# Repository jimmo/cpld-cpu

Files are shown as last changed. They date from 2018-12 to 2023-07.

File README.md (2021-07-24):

## CPLD CPU

This is a project to create a demonstration CPU that is simple enough to be able to watch its execution but also able to do something almost useful.

It was inspired by the following five projects:
 - [Fourbit, by Jaromir Sukuba](http://jaromir.xf.cz/fourbit/fourbit.html). This is a 4-bit CPU made entirely from 74xx series logic.
 - [Tiny CPU in a CPLD, by Big Mess o' Wires](https://www.bigmessowires.com/cpu-in-a-cpld/). This implements a whole CPU inside a single Altera CPLD.
 - [MCPU, by Tim Böscke](https://github.com/cpldcpu/MCPU) (and [writeup, by Jean-Claude Wippler](https://jeelabs.org/2017/11/tfoc---a-minimal-computer/)). Similar to above, but using the exact CPLD that I was intending to use, and with a really well-documented and practical ISA.
 - [The Megaprocessor, by James Newman](http://megaprocessor.com/). "The Megaprocessor is a micro-processor built large. Very large." Each gate is made from through-hole transistors with LEDs on all inputs and outputs.
 - [monster6502, by TubeTime & Evil Mad Scientist Laboratories](https://monster6502.com/). A working replica of the 6502 using discrete SMT transistors, complete with loads of LEDs.

In particular the CPU design (ISA and architecture) is inspired by Fourbit, Tiny CPU, and especially MPU, while the exploded design and "LEDs everywhere" is inspired by the Megaprocessor and monster6502. While nowhere near as capable as monster6502 or the Megaprocessor, it is definitely much more budget-friendly! And it can still [compute prime numbers](pysim/cpu_ax_13/tests/primes.s) ([video](https://www.youtube.com/watch?v=ZP9e-FCwwOs)) and [drive APA102 LED strips](pysim/cpu_ax_13/tests/apa102c.s).

Also, while not a direct inspiration to this project, it's absolutely worth linking to [Breadboard 8-bit computer, by Ben Eater](https://eater.net/8bit) which is a wonderful series about a similar project.

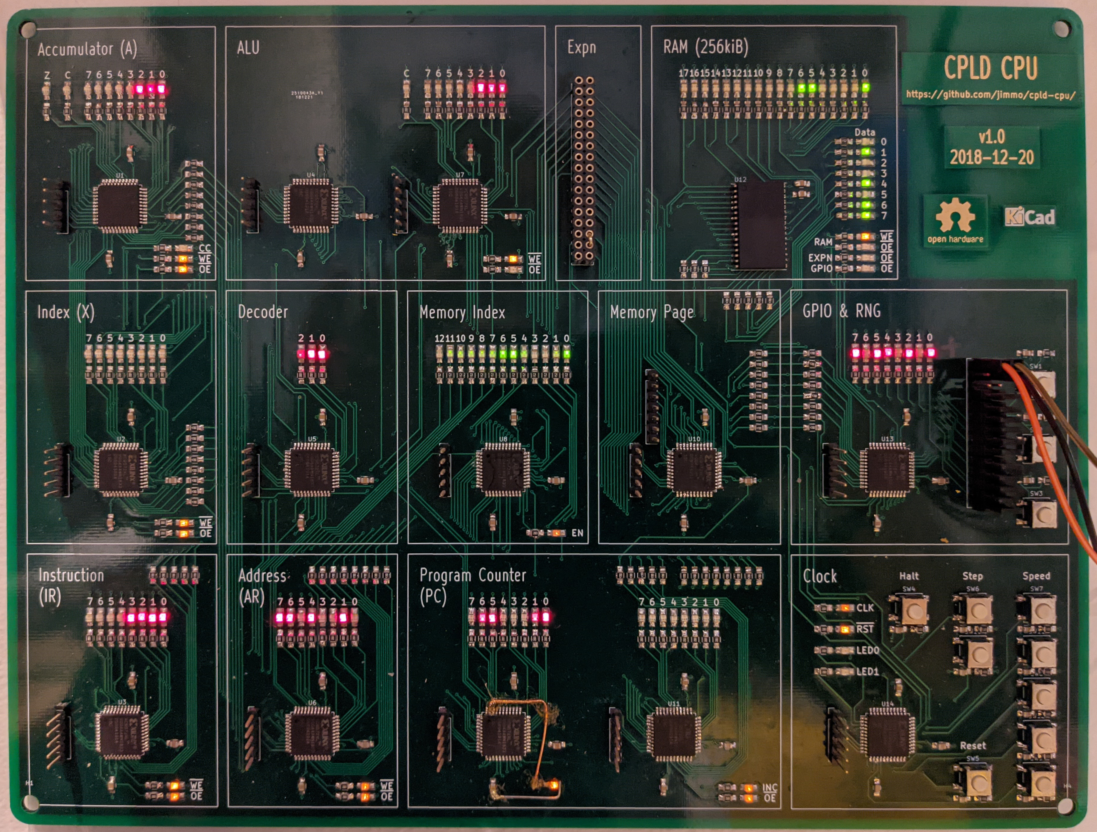
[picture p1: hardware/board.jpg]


## History

This idea started when I was teaching an introduction to "how CPUs work", and wanted something tangible to show my students. The goal is to show how simple logic circuits (i.e. starting with AND and OR gates, flip flops, and a clock) can work together to do computation. No magic required.

Initially I planned to exactly replicate the Fourbit (possibly upgraded to 8-bit), but had trouble sourcing the 74181 ALU. I found a [XC9572XL CPLD development board](http://dangerousprototypes.com/blog/2011/03/29/new-prototype-xc9572xl-cpld-development-board/) in my board collection and considered replicating the 74181 on that. CPLDs are really useful for a project like this because they do not require external flash for configuration. You can use them almost as a complete drop-in replacement. However, at this point if you're not constraining yourself to using exactly 74xx series parts, then there are several simplifications you can make in the Fourbit design.

So I set about designing a CPU where each functional component is its own CPLD. In some ways this is similar to designing a soft-CPU for an FPGA, but with the additional constraint that signals between components actually need to go via physical pins. For an 8-bit CPU, this uses up a lot of pins very quickly.

For a fun side-quest, I wrote a [logic simulator](pysim) that allows a logic circuit to be defined in Python, and simulated, much the same way that [Verilator](https://www.veripool.org/verilator/) can simulate an HDL file. This allowed me to test and iterate on some different designs, including an [exact clone of the MCPU design](pysim/cpu_a_6). Additionally the simulator allows me to stay closer to my original goal of being able to describe every logic gate, although some shortcuts were taken.

The [final design](pysim/cpu_ax_13) expands on the MCPU design, including 13-bit addressing, an index register, two-byte instruction encoding, a primitive MMU allowing addressing up to 1MiB of physical RAM, and memory-mapped IO. The memory is von Neumann, allowing for RAM and ROM to share the same bus. The simulator allowed some [programs to be written](pysim/cpu_ax_13/tests) and tested, including an assembler supporting some macro commands.

Once that was working, I translated each Python component into VHDL, and tested it on the CPLD breakout board. For example, here's the decoder ([Python](pysim/cpu_ax_13/cpu.py#L51) and [VHDL](gateware/decoder/decoder.vhd)). The most difficult part of this process, and possibly the whole project, was [uploading the gateware to the CPLD](https://blog.jimmo.id.au/2018/11/26/programming-a-xc9500xl-cpld-with-a-raspberry-pi.html). In order to keep the design simple, the clock is generated by a ring oscillator in the clock CPLD, which is a terrible idea in general but works well here.

Finally, I designed [a schematic](hardware/schematic.pdf) and [PCB layout](hardware), which mostly involved laying out 131 LEDs (and their current limiting resistors). Rather than putting both RAM and ROM into the design, it just has a single RAM chip. This means that it has no persistent program storage, and the program needs to be loaded by an external programmer (implemented using some spare pins on the memory controller).

It's a four-layer PCB and can be assembled by hand with an iron or hot air. The CPLDs are TQFP and the LEDs and resistors are all 0805.

Other than occasionally being used for teaching, I mostly keep it mounted on the wall with the clock speed set to \~5Hz, forever [computing prime numbers](pysim/cpu_ax_13/tests/primes.s). It's quite mesmerizing to [watch](https://www.youtube.com/watch?v=ZP9e-FCwwOs)!

## Features

 - All internal state visible via 131 LEDs. This includes:
   - A, X, PC, Instr, and Addr registers (including carry & zero flags).
   - Data bus (and output/input state of each connected component)
   - Memory address
   - Clock
   - Decoder state
   - GPIO
 - 8-bit accumulator
 - 8-bit index register
 - 16-bit program counter
 - 8 instructions (nor a, add a, sta, jcc, nor x, add x, stx, jnz)
 - Variable-speed clock (Hz to >100kHz), including single-instruction and single-cycle step.
 - Expansion header (allowing for memory-mapped peripherals)
 - 8-bit memory-mapped GPIO port (input and output, with jumpered LEDs on each)
 - Serial programming header

## Instruction set

The instruction set is heavily inspired by MCPU. See their [project description](https://github.com/cpldcpu/MCPU/blob/master/mcpu.pdf?raw=true) and [blog post](https://jeelabs.org/2017/11/tfoc---a-minimal-computer/) for more information. The main extension is the addition of the index register (X) as well as a jump-non-zero.

### Hardware instructions

#### nor [mem]
`A = A nor [mem + X]`

#### add
`A = A + [mem + X]`

#### sta
`[mem + X] = A`

#### jcc
Jump if carry not set.

#### norx
`X = X nor [X]`

#### addx
`X = X + [mem]`

#### stx
`[mem] = X`

#### jnz
Jump if zero flag not set.

#### Pseudo instructions

These are supported by the assembler and generate a sequence of real instructions.

#### clr
`A = 0`

#### lda
`A = [mem]`

#### not
`A = ~A`

#### sub
`A = A - [mem + X]`

#### clrx
`X = 0`

#### ldx
`X = [mem]`

#### notx
`X = ~X`

#### subx
`X = X - [mem]`

#### jmp
Unconditional jump

#### jcs
Jump if carry flag set

#### jz
Jump if zero flag set

#### shl
`A = A << 1`

#### inc
`A = A + 1`

#### dec
`A = A - 1`

#### and
`A = A & [mem + X]`

#### or
`A = A | [mem + X]`

#### nand
`A = ~(A & [mem + X])`

#### xnor
`A = ~(A ^ [mem + X])`

#### xor
`A = A ^ [mem + X]`

#### ldpg
Sets the current memory page

#### hlt
Infinite loop

#### out
(Simulator only) prints A to stdout

## Programming

There's a [MicroPython script](programmer) that can load a assembled binary via the serial programming interface (header is next to the memory controller).

## TODO

 - Much more documentation and assembly guide (I'd love to do a video series one day)
 - Better demos
 - A higher-level compiler, making better use of the MMU
 - Design a peripheral to use the expansion connector
 - Use an external clock (and find out how fast this can go).

## Ideas for future revisions

 - Separate net for the LED ground (allowing it to be disconnected).
 - Fix the missing PC_LOW LED (bodged in on the current board)
 - More LEDs (e.g. ALU current operation)

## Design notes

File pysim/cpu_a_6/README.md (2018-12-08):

This exactly implements the CPU from https://github.com/cpldcpu/MCPU

The implementation here is written to match the original VHDL as closely as possible. It's almost line for line identical other than syntax changes to match pysim.

I've added an assembler that generates the same machine code, including the macro ops described such as `sub`, etc plus a few more. Additionally, the assembler automatically generates some useful constant values at known locations, such as `one`, `allones`, etc, and a simple memory-mapped output interface.

There are three demos:
 - tests/count.s -- demonstrates counting up and down with output
 - tests/mem.s -- uses self-modifying code to fill RAM with a sequence
 - tests/prime.s -- copied from https://jeelabs.org/2017/11/tfoc---a-minimal-computer/

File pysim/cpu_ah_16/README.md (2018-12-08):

This is a more complicated design that allows for 8 registers and 16-bit memory addressing. It's loosely based on http://jaromir.xf.cz/fourbit/fourbit.html

The overall design is:
* 8-bit registers, 16-bit memory addressing.
* Fixed number of cycles (4) for all instructions.
* Single-byte instructions.
* Operations are reg->reg, reg->ram, ram->reg, alu->reg.
* Specific registers can be combined and used as memory addresses.
* Load instructions have 4 bits of immediate data.

There's an assembler which also provides some simple macros, and an extremely simple "compiler".

It would be an interesting exercise to implement some basic optimizations for the compiler, e.g. taking advantage of the number of registers to avoid memory reads/writes on every statement.

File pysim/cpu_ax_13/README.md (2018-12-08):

This adds both the index register and two-byte instructions. Each instruction is a 3-bit op, and 13-bit address.

The memory controller also implements paged addressing, with two pages, allowing for 1MiB of addressable RAM.
There are two memory-mapped registers which set the physical address for that page (in 4k intervals).

So each address is a 1-bit page number (_n)), and a 12-bit offset (_addr_). The physical address will be the PR[_n_] * 4k + _addr_.

Two basic memory-mapped perhipherals are available: LED output and RNG.

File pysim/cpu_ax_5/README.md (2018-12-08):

This is an extension of cpu_a_6 to add an index register, used by `add`, `nor` and `sta` to modify the memory address. It also adds a 'jnz' conditional jump. The index register can be accessed via the `norx`, `addx` and `stx` instructions. The assembler also provides the same set of macro instructions as for the accumulator.

Having an index register allows working with arrays without needing self-modifying code.

Note that the extra four instructions cost a 1 bit of address-width, which leaves only 32 bytes of accessible RAM... This isn't a very useful CPU! See cpu_ax_13 which adds two-byte instructions, allowing for a 12-bit address space, as well as a banked memory controller.

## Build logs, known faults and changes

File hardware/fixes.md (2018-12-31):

## GPIO RNG
* addr(1) and addr(2) are connected to the opposite nets on the bus. (Workaround in UCF).

## Program counter
* Missing WE LED.

## Mem page
* Missing pull-downs on programmer pins. (Workaround with programmer driving low).

## RAM
* Doesn't seem to drive the data bus with enough current for the LEDs.

## General
* Orange LEDs are too dim.

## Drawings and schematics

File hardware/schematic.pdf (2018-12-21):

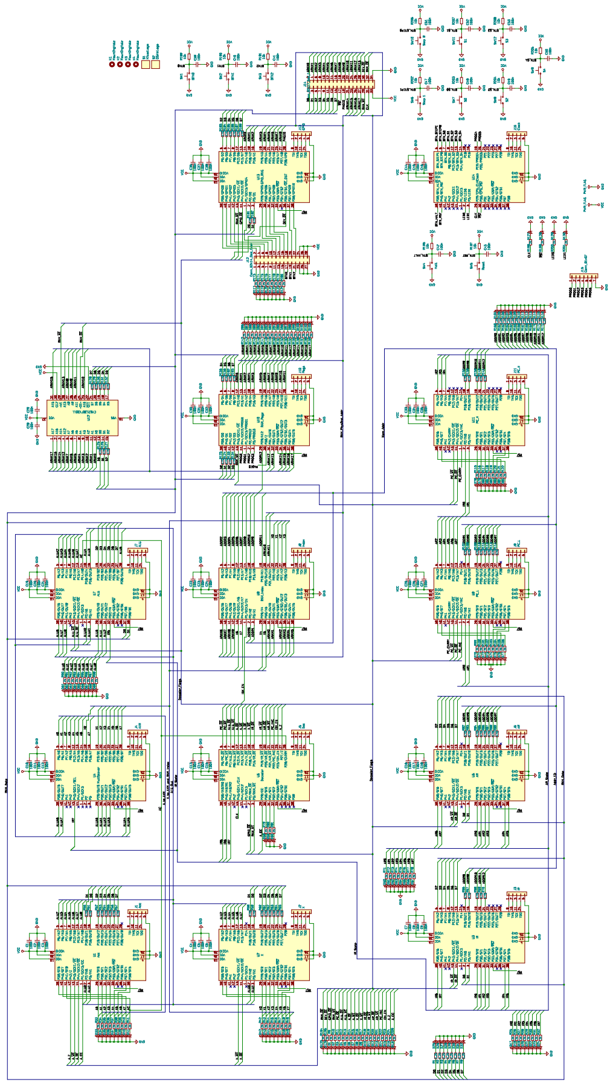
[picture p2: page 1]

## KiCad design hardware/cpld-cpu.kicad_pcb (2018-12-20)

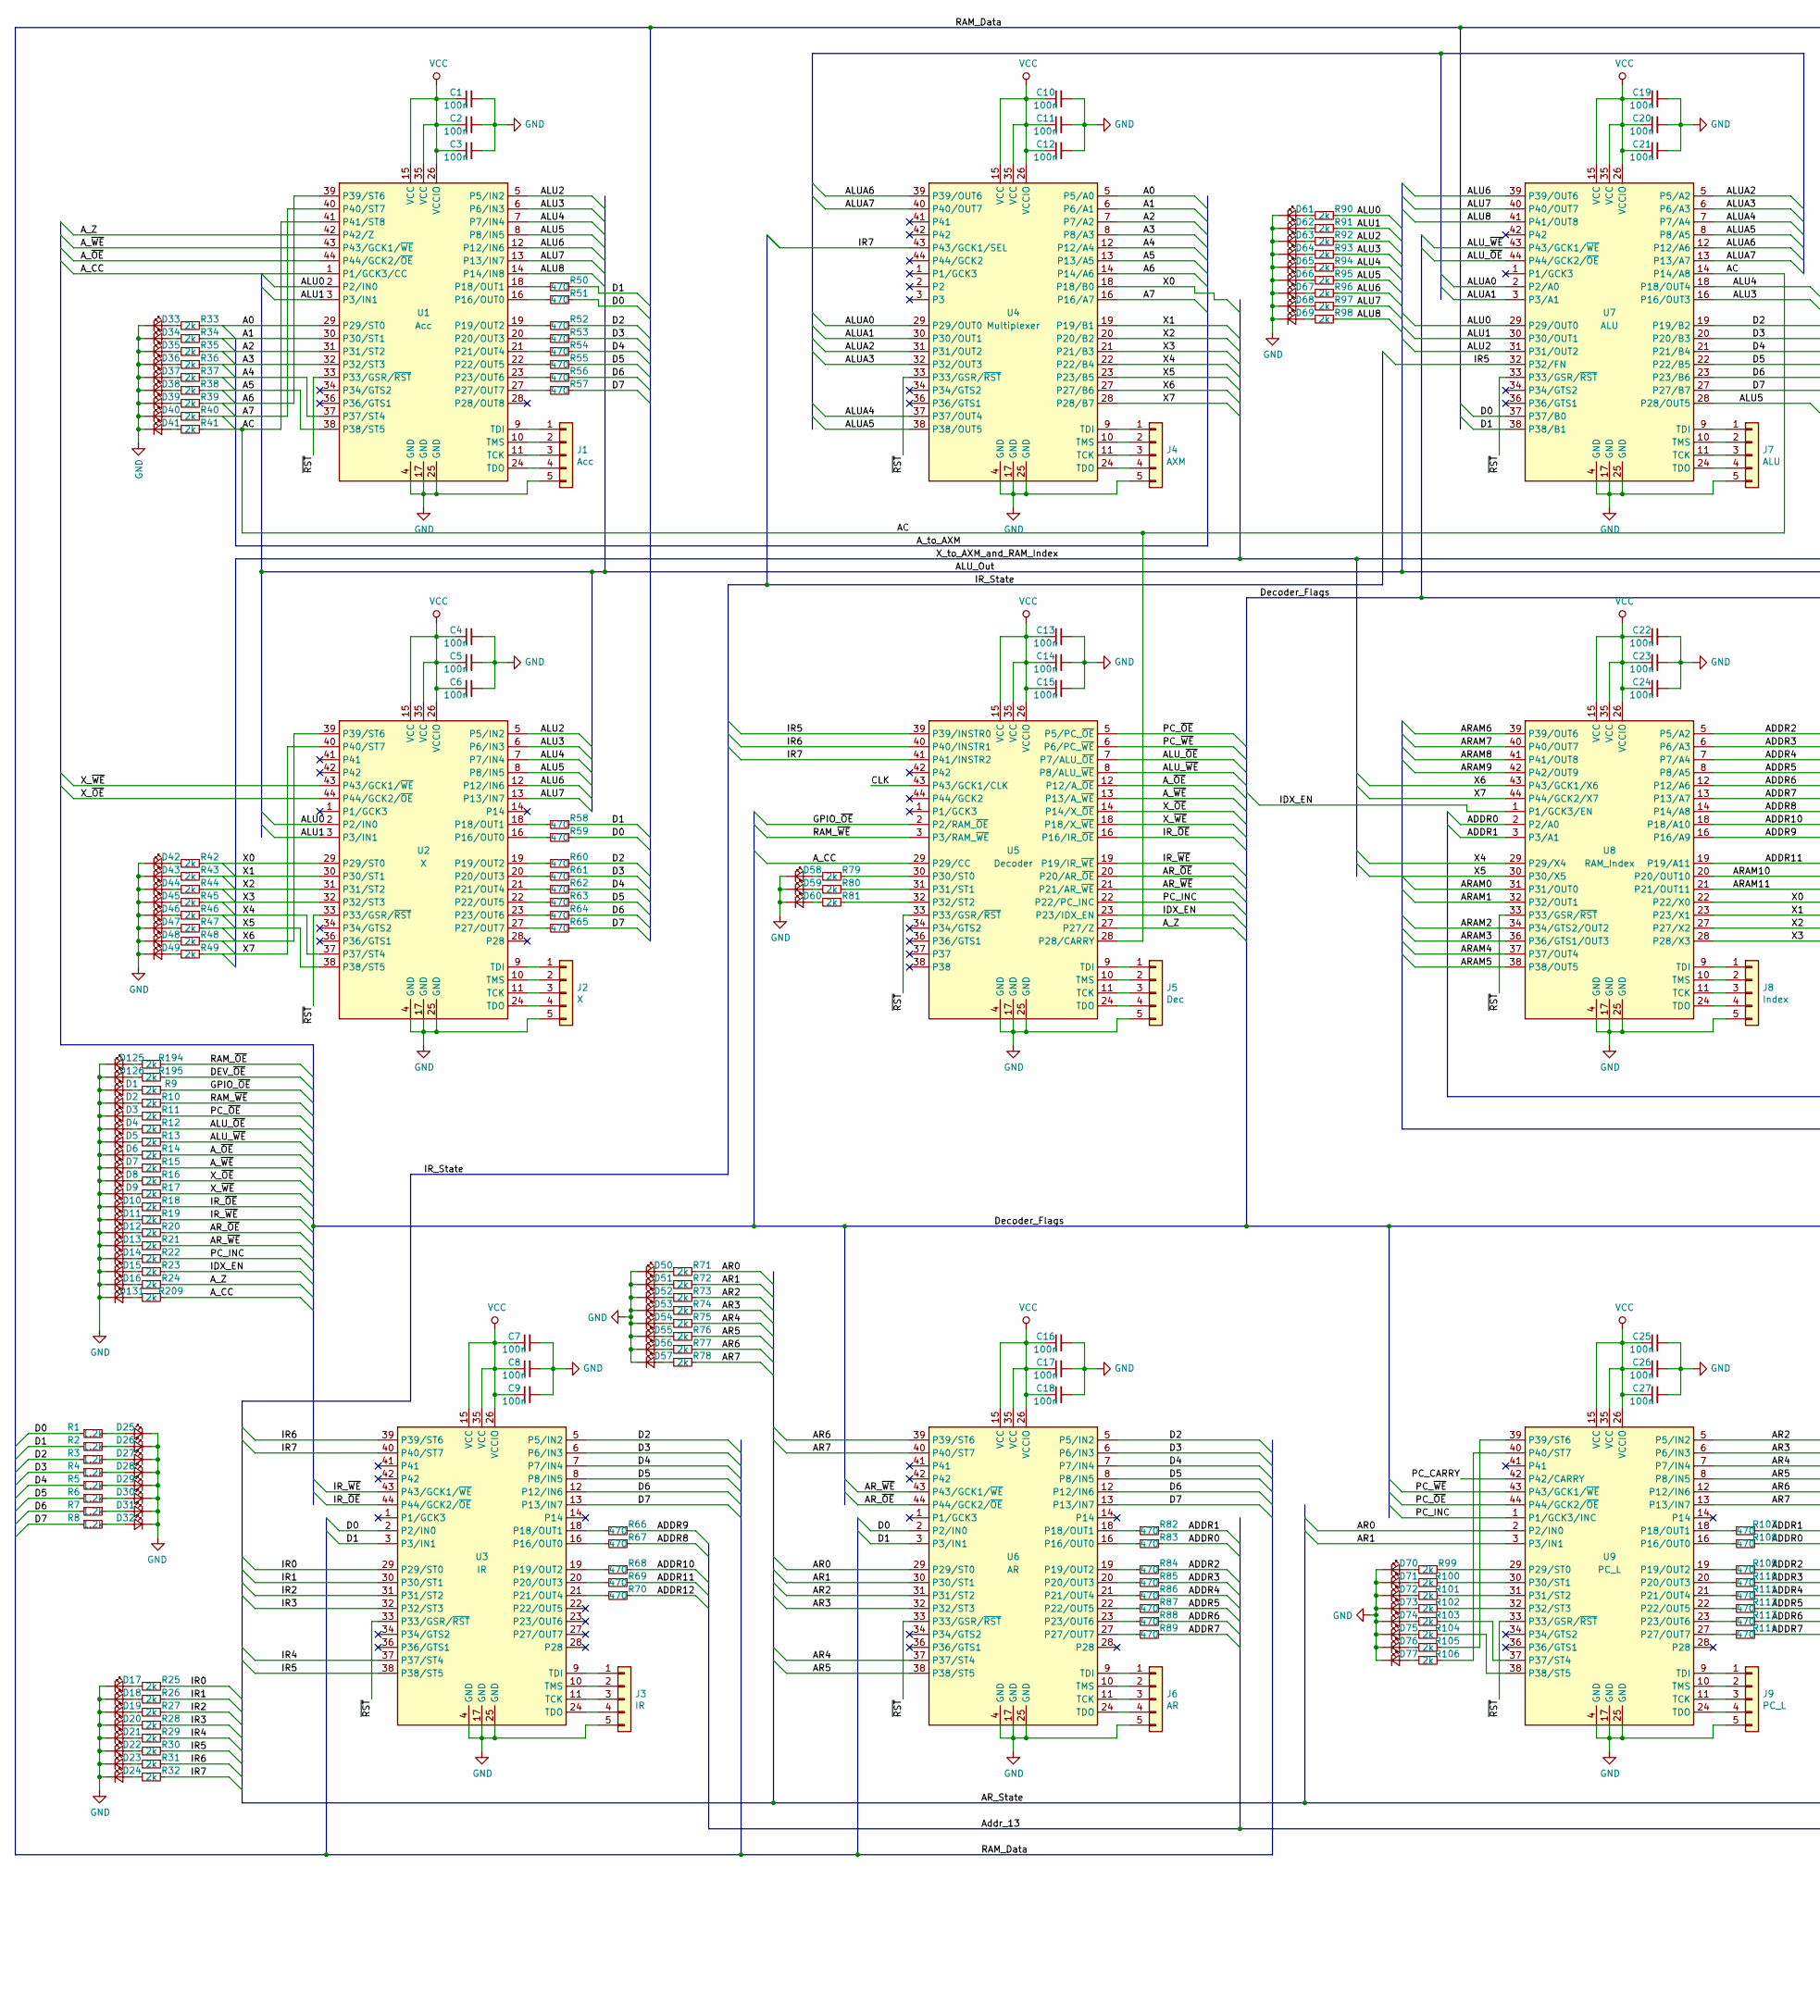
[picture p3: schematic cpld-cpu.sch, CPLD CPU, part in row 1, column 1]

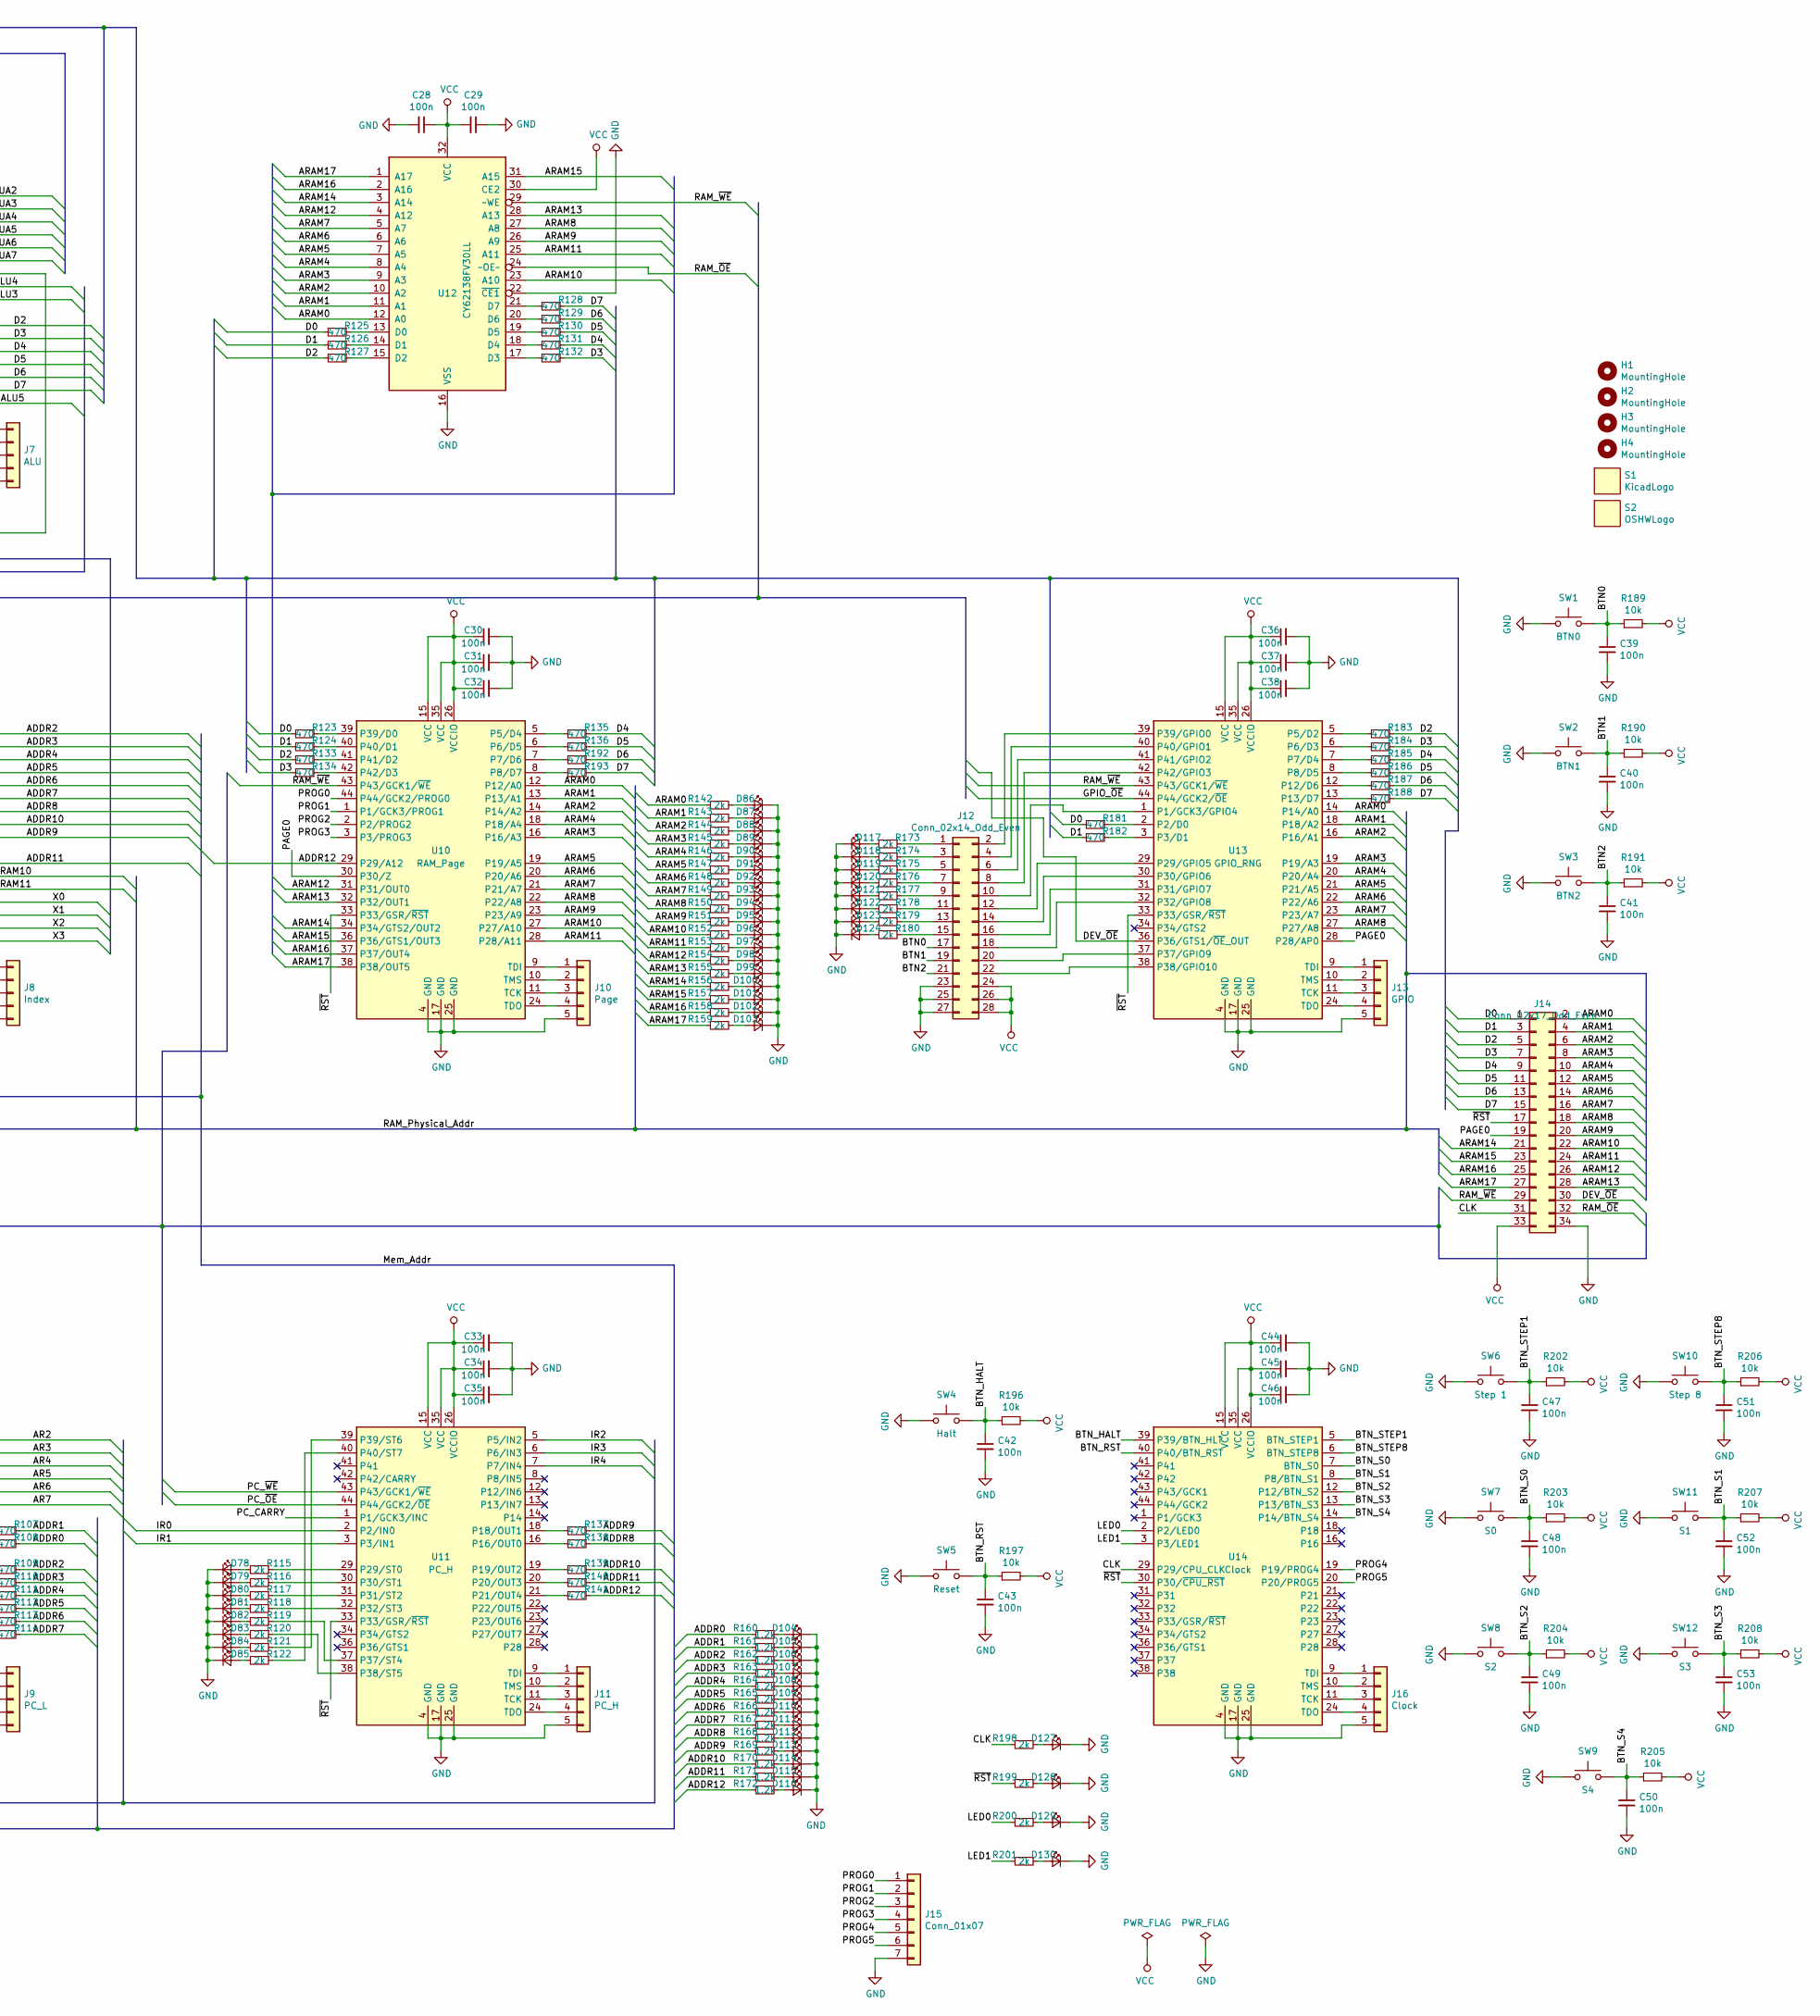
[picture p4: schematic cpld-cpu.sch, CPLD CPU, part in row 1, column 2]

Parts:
C1, C2, C3, C4, C5, C6, C7, C8, C9, C10, C11, C12, C13, C14, C15, C16, C17, C18, C19, C20, C21, C22, C23, C24, C25, C26, C27, C28, C29, C30, C31, C32, C33, C34, C35, C36, C37, C38, C39, C40, C41, C42, C43, C44, C45, C46, C47, C48, C49, C50, C51, C52, C53: 100n; C_0805_HandSoldering
D1, D2, D3, D4, D5, D6, D7, D8, D9, D10, D11, D12, D13, D14, D15, D16, D17, D18, D19, D20, D21, D22, D23, D24, D25, D26, D27, D28, D29, D30, D31, D32, D33, D34, D35, D36, D37, D38, D39, D40, D41, D42, D43, D44, D45, D46, D47, D48, D49, D50, D51, D52, D53, D54, D55, D56, D57, D58, D59, D60, D61, D62, D63, D64, D65, D66, D67, D68, D69, D70, D71, D72, D73, D74, D75, D76, D77, D78, D79, D80, D81, D82, D83, D84, D85, D86, D87, D88, D89, D90, D91, D92, D93, D94, D95, D96, D97, D98, D99, D100, D101, D102, D103, D104, D105, D106, D107, D108, D109, D110, D111, D112, D113, D114, D115, D116, D117, D118, D119, D120, D121, D122, D123, D124, D125, D126, D127, D128, D129, D130, D131: LED_Small; LED_0805_HandSoldering
H1, H2, H3, H4: MountingHole; MountingHole_4.3mm_M4
J1: Acc; Pin_Header_Straight_1x05_Pitch2.54mm
J2: X; Pin_Header_Straight_1x05_Pitch2.54mm
J3: IR; Pin_Header_Straight_1x05_Pitch2.54mm
J4: AXM; Pin_Header_Straight_1x05_Pitch2.54mm
J5: Dec; Pin_Header_Straight_1x05_Pitch2.54mm
J6: AR; Pin_Header_Straight_1x05_Pitch2.54mm
J7: ALU; Pin_Header_Straight_1x05_Pitch2.54mm
J8: Index; Pin_Header_Straight_1x05_Pitch2.54mm
J9: PC_L; Pin_Header_Straight_1x05_Pitch2.54mm
J10: Page; Pin_Header_Straight_1x05_Pitch2.54mm
J11: PC_H; Pin_Header_Straight_1x05_Pitch2.54mm
J12: Conn_02x14_Odd_Even; Pin_Header_Straight_2x14_Pitch2.54mm
J13: GPIO; Pin_Header_Straight_1x05_Pitch2.54mm
J14: Conn_02x17_Odd_Even; Pin_Header_Straight_2x17_Pitch2.54mm
J15: Conn_01x07; Pin_Header_Straight_1x07_Pitch2.54mm
J16: Clock; Pin_Header_Straight_1x05_Pitch2.54mm
R1, R2, R3, R4, R5, R6, R7, R8, R160, R161, R162, R163, R164, R165, R166, R167, R168, R169, R170, R171, R172: 1.2k; R_0805_HandSoldering
R9, R10, R11, R12, R13, R14, R15, R16, R17, R18, R19, R20, R21, R22, R23, R24, R25, R26, R27, R28, R29, R30, R31, R32, R33, R34, R35, R36, R37, R38, R39, R40, R41, R42, R43, R44, R45, R46, R47, R48, R49, R71, R72, R73, R74, R75, R76, R77, R78, R79, R80, R81, R90, R91, R92, R93, R94, R95, R96, R97, R98, R99, R100, R101, R102, R103, R104, R105, R106, R115, R116, R117, R118, R119, R120, R121, R122, R142, R143, R144, R145, R146, R147, R148, R149, R150, R151, R152, R153, R154, R155, R156, R157, R158, R159, R173, R174, R175, R176, R177, R178, R179, R180, R194, R195, R198, R199, R200, R201, R209: 2k; R_0805_HandSoldering
R50, R51, R52, R53, R54, R55, R56, R57, R58, R59, R60, R61, R62, R63, R64, R65, R66, R67, R68, R69, R70, R82, R83, R84, R85, R86, R87, R88, R89, R107, R108, R109, R110, R111, R112, R113, R114, R123, R124, R125, R126, R127, R128, R129, R130, R131, R132, R133, R134, R135, R136, R137, R138, R139, R140, R141, R181, R182, R183, R184, R185, R186, R187, R188, R192, R193: 470; R_0805_HandSoldering
R189, R190, R191, R196, R197, R202, R203, R204, R205, R206, R207, R208: 10k; R_0805_HandSoldering
S1: KicadLogo; Symbol_KiCAD-Logo_CopperAndSilkScreenTop
S2: OSHWLogo; OSHW-Logo2_14.6x12mm_Copper_Top
SW1: BTN0; SW_SPST_B3S-1000
SW2: BTN1; SW_SPST_B3S-1000
SW3: BTN2; SW_SPST_B3S-1000
SW4: Halt; SW_SPST_B3S-1000
SW5: Reset; SW_SPST_B3S-1000
SW6: Step 1; SW_SPST_B3S-1000
SW7: S0; SW_SPST_B3S-1000
SW8: S2; SW_SPST_B3S-1000
SW9: S4; SW_SPST_B3S-1000
SW10: Step 8; SW_SPST_B3S-1000
SW11: S1; SW_SPST_B3S-1000
SW12: S3; SW_SPST_B3S-1000
U1: Acc; TQFP-44_10x10mm_Pitch0.8mm
U2: X; TQFP-44_10x10mm_Pitch0.8mm
U3: IR; TQFP-44_10x10mm_Pitch0.8mm
U4: Multiplexer; TQFP-44_10x10mm_Pitch0.8mm
U5: Decoder; TQFP-44_10x10mm_Pitch0.8mm
U6: AR; TQFP-44_10x10mm_Pitch0.8mm
U7: ALU; TQFP-44_10x10mm_Pitch0.8mm
U8: RAM_Index; TQFP-44_10x10mm_Pitch0.8mm
U9: PC_L; TQFP-44_10x10mm_Pitch0.8mm
U10: RAM_Page; TQFP-44_10x10mm_Pitch0.8mm
U11: PC_H; TQFP-44_10x10mm_Pitch0.8mm
U12: CY62138FV30LL; TSOP-II-32_21.0x10.2mm_Pitch1.27mm
U13: GPIO_RNG; TQFP-44_10x10mm_Pitch0.8mm
U14: Clock; TQFP-44_10x10mm_Pitch0.8mm

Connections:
/A0: R33.1, U1.29 (P29/ST0), U4.5 (P5/A0)
/A1: R34.1, U1.30 (P30/ST1), U4.6 (P6/A1)
/A2: R35.1, U1.31 (P31/ST2), U4.7 (P7/A2)
/A3: R36.1, U1.32 (P32/ST3), U4.8 (P8/A3)
/A4: R37.1, U1.37 (P37/ST4), U4.12 (P12/A4)
/A5: R38.1, U1.38 (P38/ST5), U4.13 (P13/A5)
/A6: R39.1, U1.39 (P39/ST6), U4.14 (P14/A6)
/A7: R40.1, U1.40 (P40/ST7), U4.16 (P16/A7)
/AC: R41.1, U1.41 (P41/ST8), U5.28 (P28/CARRY), U7.14 (P14/A8)
/ADDR0: R83.1, R108.1, R160.1, U8.2 (P2/A0)
/ADDR1: R82.1, R107.1, R161.1, U8.3 (P3/A1)
/ADDR2: R84.1, R109.1, R162.1, U8.5 (P5/A2)
/ADDR3: R85.1, R110.1, R163.1, U8.6 (P6/A3)
/ADDR4: R86.1, R111.1, R164.1, U8.7 (P7/A4)
/ADDR5: R87.1, R112.1, R165.1, U8.8 (P8/A5)
/ADDR6: R88.1, R113.1, R166.1, U8.12 (P12/A6)
/ADDR7: R89.1, R114.1, R167.1, U8.13 (P13/A7)
/ADDR8: R67.1, R138.1, R168.1, U8.14 (P14/A8)
/ADDR9: R66.1, R137.1, R169.1, U8.16 (P16/A9)
/ADDR10: R68.1, R139.1, R170.1, U8.18 (P18/A10)
/ADDR11: R69.1, R140.1, R171.1, U8.19 (P19/A11)
/ADDR12: R70.1, R141.1, R172.1, U10.29 (P29/A12)
/ALU0: R90.1, U1.2 (P2/IN0), U2.2 (P2/IN0), U7.29 (P29/OUT0)
/ALU1: R91.1, U1.3 (P3/IN1), U2.3 (P3/IN1), U7.30 (P30/OUT1)
/ALU2: R92.1, U1.5 (P5/IN2), U2.5 (P5/IN2), U7.31 (P31/OUT2)
/ALU3: R93.1, U1.6 (P6/IN3), U2.6 (P6/IN3), U7.16 (P16/OUT3)
/ALU4: R94.1, U1.7 (P7/IN4), U2.7 (P7/IN4), U7.18 (P18/OUT4)
/ALU5: R95.1, U1.8 (P8/IN5), U2.8 (P8/IN5), U7.28 (P28/OUT5)
/ALU6: R96.1, U1.12 (P12/IN6), U2.12 (P12/IN6), U7.39 (P39/OUT6)
/ALU7: R97.1, U1.13 (P13/IN7), U2.13 (P13/IN7), U7.40 (P40/OUT7)
/ALU8: R98.1, U1.14 (P14/IN8), U7.41 (P41/OUT8)
/ALUA0: U4.29 (P29/OUT0), U7.2 (P2/A0)
/ALUA1: U4.30 (P30/OUT1), U7.3 (P3/A1)
/ALUA2: U4.31 (P31/OUT2), U7.5 (P5/A2)
/ALUA3: U4.32 (P32/OUT3), U7.6 (P6/A3)
/ALUA4: U4.37 (P37/OUT4), U7.7 (P7/A4)
/ALUA5: U4.38 (P38/OUT5), U7.8 (P8/A5)
/ALUA6: U4.39 (P39/OUT6), U7.12 (P12/A6)
/ALUA7: U4.40 (P40/OUT7), U7.13 (P13/A7)
/ALU_~OE~: R12.1, U5.7 (P7/ALU_~OE~), U7.44 (P44/GCK2/~OE~)
/ALU_~WE~: R13.1, U5.8 (P8/ALU_~WE~), U7.43 (P43/GCK1/~WE~)
/AR0: R71.1, U6.29 (P29/ST0), U9.2 (P2/IN0)
/AR1: R72.1, U6.30 (P30/ST1), U9.3 (P3/IN1)
/AR2: R73.1, U6.31 (P31/ST2), U9.5 (P5/IN2)
/AR3: R74.1, U6.32 (P32/ST3), U9.6 (P6/IN3)
/AR4: R75.1, U6.37 (P37/ST4), U9.7 (P7/IN4)
/AR5: R76.1, U6.38 (P38/ST5), U9.8 (P8/IN5)
/AR6: R77.1, U6.39 (P39/ST6), U9.12 (P12/IN6)
/AR7: R78.1, U6.40 (P40/ST7), U9.13 (P13/IN7)
/ARAM0: J14.2, R142.1, U8.31 (P31/OUT0), U10.12 (P12/A0), U12.12 (A0), U13.14 (P14/A0)
/ARAM1: J14.4, R143.1, U8.32 (P32/OUT1), U10.13 (P13/A1), U12.11 (A1), U13.18 (P18/A2)
/ARAM2: J14.6, R144.1, U8.34 (P34/GTS2/OUT2), U10.14 (P14/A2), U12.10 (A2), U13.16 (P16/A1)
/ARAM3: J14.8, R145.1, U8.36 (P36/GTS1/OUT3), U10.16 (P16/A3), U12.9 (A3), U13.19 (P19/A3)
/ARAM4: J14.10, R146.1, U8.37 (P37/OUT4), U10.18 (P18/A4), U12.8 (A4), U13.20 (P20/A4)
/ARAM5: J14.12, R147.1, U8.38 (P38/OUT5), U10.19 (P19/A5), U12.7 (A5), U13.21 (P21/A5)
/ARAM6: J14.14, R148.1, U8.39 (P39/OUT6), U10.20 (P20/A6), U12.6 (A6), U13.22 (P22/A6)
/ARAM7: J14.16, R149.1, U8.40 (P40/OUT7), U10.21 (P21/A7), U12.5 (A7), U13.23 (P23/A7)
/ARAM8: J14.18, R150.1, U8.41 (P41/OUT8), U10.22 (P22/A8), U12.27 (A8), U13.27 (P27/A8)
/ARAM9: J14.20, R151.1, U8.42 (P42/OUT9), U10.23 (P23/A9), U12.26 (A9)
/ARAM10: J14.22, R152.1, U8.20 (P20/OUT10), U10.27 (P27/A10), U12.23 (A10)
/ARAM11: J14.24, R153.1, U8.21 (P21/OUT11), U10.28 (P28/A11), U12.25 (A11)
/ARAM12: J14.26, R154.1, U10.31 (P31/OUT0), U12.4 (A12)
/ARAM13: J14.28, R155.1, U10.32 (P32/OUT1), U12.28 (A13)
/ARAM14: J14.21, R156.1, U10.34 (P34/GTS2/OUT2), U12.3 (A14)
/ARAM15: J14.23, R157.1, U10.36 (P36/GTS1/OUT3), U12.31 (A15)
/ARAM16: J14.25, R158.1, U10.37 (P37/OUT4), U12.2 (A16)
/ARAM17: J14.27, R159.1, U10.38 (P38/OUT5), U12.1 (A17)
/AR_~OE~: R20.1, U5.20 (P20/AR_~OE~), U6.44 (P44/GCK2/~OE~)
/AR_~WE~: R21.1, U5.21 (P21/AR_~WE~), U6.43 (P43/GCK1/~WE~)
/A_CC: R209.1, U1.1 (P1/GCK3/CC), U5.29 (P29/CC)
/A_Z: R24.1, U1.42 (P42/Z), U5.27 (P27/Z)
/A_~OE~: R14.1, U1.44 (P44/GCK2/~OE~), U5.12 (P12/A_~OE~)
/A_~WE~: R15.1, U1.43 (P43/GCK1/~WE~), U5.13 (P13/A_~WE~)
/BTN0: C39.1, J12.17, R189.1, SW1.2
/BTN1: C40.1, J12.19, R190.1, SW2.2
/BTN2: C41.1, J12.21, R191.1, SW3.2
/BTN_HALT: C42.1, R196.1, SW4.2, U14.39 (P39/BTN_HLT)
/BTN_RST: C43.1, R197.1, SW5.2, U14.40 (P40/BTN_RST)
/BTN_S0: C48.1, R203.1, SW7.2, U14.7 (BTN_S0)
/BTN_S1: C52.1, R207.1, SW11.2, U14.8 (P8/BTN_S1)
/BTN_S2: C49.1, R204.1, SW8.2, U14.12 (P12/BTN_S2)
/BTN_S3: C53.1, R208.1, SW12.2, U14.13 (P13/BTN_S3)
/BTN_S4: C50.1, R205.1, SW9.2, U14.14 (P14/BTN_S4)
/BTN_STEP1: C47.1, R202.1, SW6.2, U14.5 (BTN_STEP1)
/BTN_STEP8: C51.1, R206.1, SW10.2, U14.6 (BTN_STEP8)
/CLK: J14.31, R198.1, U5.43 (P43/GCK1/CLK), U14.29 (P29/CPU_CLK)
/D0: J14.1, R1.1, R51.1, R59.1, R123.2, R125.2, R181.2, U3.2 (P2/IN0), U6.2 (P2/IN0), U7.37 (P37/B0)
/D1: J14.3, R2.1, R50.1, R58.1, R124.2, R126.2, R182.2, U3.3 (P3/IN1), U6.3 (P3/IN1), U7.38 (P38/B1)
/D2: J14.5, R3.1, R52.1, R60.1, R127.2, R133.2, R183.1, U3.5 (P5/IN2), U6.5 (P5/IN2), U7.19 (P19/B2)
/D3: J14.7, R4.1, R53.1, R61.1, R132.1, R134.2, R184.1, U3.6 (P6/IN3), U6.6 (P6/IN3), U7.20 (P20/B3)
/D4: J14.9, R5.1, R54.1, R62.1, R131.1, R135.1, R185.1, U3.7 (P7/IN4), U6.7 (P7/IN4), U7.21 (P21/B4)
/D5: J14.11, R6.1, R55.1, R63.1, R130.1, R136.1, R186.1, U3.8 (P8/IN5), U6.8 (P8/IN5), U7.22 (P22/B5)
/D6: J14.13, R7.1, R56.1, R64.1, R129.1, R187.1, R192.1, U3.12 (P12/IN6), U6.12 (P12/IN6), U7.23 (P23/B6)
/D7: J14.15, R8.1, R57.1, R65.1, R128.1, R188.1, R193.1, U3.13 (P13/IN7), U6.13 (P13/IN7), U7.27 (P27/B7)
/DEV_~OE~: J14.30, R195.1, U13.36 (P36/GTS1/~OE~_OUT)
/GPIO_~OE~: R9.1, U5.2 (P2/RAM_~OE~), U13.44 (P44/GCK2/~OE~)
/IDX_EN: R23.1, U5.23 (P23/IDX_EN), U8.1 (P1/GCK3/EN)
/IR0: R25.1, U3.29 (P29/ST0), U11.2 (P2/IN0)
/IR1: R26.1, U3.30 (P30/ST1), U11.3 (P3/IN1)
/IR2: R27.1, U3.31 (P31/ST2), U11.5 (P5/IN2)
/IR3: R28.1, U3.32 (P32/ST3), U11.6 (P6/IN3)
/IR4: R29.1, U3.37 (P37/ST4), U11.7 (P7/IN4)
/IR5: R30.1, U3.38 (P38/ST5), U5.39 (P39/INSTR0), U7.32 (P32/FN)
/IR6: R31.1, U3.39 (P39/ST6), U5.40 (P40/INSTR1)
/IR7: R32.1, U3.40 (P40/ST7), U4.43 (P43/GCK1/SEL), U5.41 (P41/INSTR2)
/IR_~OE~: R18.1, U3.44 (P44/GCK2/~OE~), U5.16 (P16/IR_~OE~)
/IR_~WE~: R19.1, U3.43 (P43/GCK1/~WE~), U5.19 (P19/IR_~WE~)
/LED0: R200.1, U14.2 (P2/LED0)
/LED1: R201.1, U14.3 (P3/LED1)
/PAGE0: J14.19, U10.30 (P30/Z), U13.28 (P28/AP0)
/PC_CARRY: U9.42 (P42/CARRY), U11.1 (P1/GCK3/INC)
/PC_INC: R22.1, U5.22 (P22/PC_INC), U9.1 (P1/GCK3/INC)
/PC_~OE~: R11.1, U5.5 (P5/PC_~OE~), U9.44 (P44/GCK2/~OE~), U11.44 (P44/GCK2/~OE~)
/PC_~WE~: U5.6 (P6/PC_~WE~), U9.43 (P43/GCK1/~WE~), U11.43 (P43/GCK1/~WE~)
/PROG0: J15.1, U10.44 (P44/GCK2/PROG0)
/PROG1: J15.2, U10.1 (P1/GCK3/PROG1)
/PROG2: J15.3, U10.2 (P2/PROG2)
/PROG3: J15.4, U10.3 (P3/PROG3)
/PROG4: J15.5, U14.19 (P19/PROG4)
/PROG5: J15.6, U14.20 (P20/PROG5)
/RAM_~OE~: J14.32, R194.1, U12.24 (~~OE~~)
/RAM_~WE~: J14.29, R10.1, U5.3 (P3/RAM_~WE~), U10.43 (P43/GCK1/~WE~), U12.29 (~~WE~), U13.43 (P43/GCK1/~WE~)
/X0: R42.1, U2.29 (P29/ST0), U4.18 (P18/B0), U8.22 (P22/X0)
/X1: R43.1, U2.30 (P30/ST1), U4.19 (P19/B1), U8.23 (P23/X1)
/X2: R44.1, U2.31 (P31/ST2), U4.20 (P20/B2), U8.27 (P27/X2)
/X3: R45.1, U2.32 (P32/ST3), U4.21 (P21/B3), U8.28 (P28/X3)
/X4: R46.1, U2.37 (P37/ST4), U4.22 (P22/B4), U8.29 (P29/X4)
/X5: R47.1, U2.38 (P38/ST5), U4.23 (P23/B5), U8.30 (P30/X5)
/X6: R48.1, U2.39 (P39/ST6), U4.27 (P27/B6), U8.43 (P43/GCK1/X6)
/X7: R49.1, U2.40 (P40/ST7), U4.28 (P28/B7), U8.44 (P44/GCK2/X7)
/X_~OE~: R16.1, U2.44 (P44/GCK2/~OE~), U5.14 (P14/X_~OE~)
/X_~WE~: R17.1, U2.43 (P43/GCK1/~WE~), U5.18 (P18/X_~WE~)
/~RST~: J14.17, R199.1, U1.33 (P33/GSR/~RST), U2.33 (P33/GSR/~RST), U3.33 (P33/GSR/~RST), U4.33 (P33/GSR/~RST), U5.33 (P33/GSR/~RST), U6.33 (P33/GSR/~RST), U7.33 (P33/GSR/~RST), U8.33 (P33/GSR/~RST), U9.33 (P33/GSR/~RST), U10.33 (P33/GSR/~RST), U11.33 (P33/GSR/~RST), U13.33 (P33/GSR/~RST), U14.30 (P30/~CPU_RST~)
GND: C1.2, C2.2, C3.2, C4.2, C5.2, C6.2, C7.2, C8.2, C9.2, C10.2, C11.2, C12.2, C13.2, C14.2, C15.2, C16.2, C17.2, C18.2, C19.2, C20.2, C21.2, C22.2, C23.2, C24.2, C25.2, C26.2, C27.2, C28.2, C29.1, C30.2, C31.2, C32.2, C33.2, C34.2, C35.2, C36.2, C37.2, C38.2, C39.2, C40.2, C41.2, C42.2, C43.2, C44.2, C45.2, C46.2, C47.2, C48.2, C49.2, C50.2, C51.2, C52.2, C53.2, D1.1 (K), D2.1 (K), D3.1 (K), D4.1 (K), D5.1 (K), D6.1 (K), D7.1 (K), D8.1 (K), D9.1 (K), D10.1 (K), D11.1 (K), D12.1 (K), D13.1 (K), D14.1 (K), D15.1 (K), D16.1 (K), D17.1 (K), D18.1 (K), D19.1 (K), D20.1 (K), D21.1 (K), D22.1 (K), D23.1 (K), D24.1 (K), D25.1 (K), D26.1 (K), D27.1 (K), D28.1 (K), D29.1 (K), D30.1 (K), D31.1 (K), D32.1 (K), D33.1 (K), D34.1 (K), D35.1 (K), D36.1 (K), D37.1 (K), D38.1 (K), D39.1 (K), D40.1 (K), D41.1 (K), D42.1 (K), D43.1 (K), D44.1 (K), D45.1 (K), D46.1 (K), D47.1 (K), D48.1 (K), D49.1 (K), D50.1 (K), D51.1 (K), D52.1 (K), D53.1 (K), D54.1 (K), D55.1 (K), D56.1 (K), D57.1 (K), D58.1 (K), D59.1 (K), D60.1 (K), D61.1 (K), D62.1 (K), D63.1 (K), D64.1 (K), D65.1 (K), D66.1 (K), D67.1 (K), D68.1 (K), D69.1 (K), D70.1 (K), D71.1 (K), D72.1 (K), D73.1 (K), D74.1 (K), D75.1 (K), D76.1 (K), D77.1 (K), D78.1 (K), D79.1 (K), D80.1 (K), D81.1 (K), D82.1 (K), D83.1 (K), D84.1 (K), D85.1 (K), D86.1 (K), D87.1 (K), D88.1 (K), D89.1 (K), D90.1 (K), D91.1 (K), D92.1 (K), D93.1 (K), D94.1 (K), D95.1 (K), D96.1 (K), D97.1 (K), D98.1 (K), D99.1 (K), D100.1 (K), D101.1 (K), D102.1 (K), D103.1 (K), D104.1 (K), D105.1 (K), D106.1 (K), D107.1 (K), D108.1 (K), D109.1 (K), D110.1 (K), D111.1 (K), D112.1 (K), D113.1 (K), D114.1 (K), D115.1 (K), D116.1 (K), D117.1 (K), D118.1 (K), D119.1 (K), D120.1 (K), D121.1 (K), D122.1 (K), D123.1 (K), D124.1 (K), D125.1 (K), D126.1 (K), D127.1 (K), D128.1 (K), D129.1 (K), D130.1 (K), D131.1 (K), J1.5, J2.5, J3.5, J4.5, J5.5, J6.5, J7.5, J8.5, J9.5, J10.5, J11.5, J12.23, J12.25, J12.27, J13.5, J14.34, J15.7, J16.5, SW1.1, SW2.1, SW3.1, SW4.1, SW5.1, SW6.1, SW7.1, SW8.1, SW9.1, SW10.1, SW11.1, SW12.1, U1.4 (GND), U1.17 (GND), U1.25 (GND), U2.4 (GND)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
unnamed: D1.2 (A), R9.2
unnamed: D2.2 (A), R10.2
unnamed: D3.2 (A), R11.2
unnamed: D4.2 (A), R12.2
unnamed: D5.2 (A), R13.2
unnamed: D6.2 (A), R14.2
unnamed: D7.2 (A), R15.2
unnamed: D8.2 (A), R16.2
unnamed: D9.2 (A), R17.2
unnamed: D10.2 (A), R18.2
unnamed: D11.2 (A), R19.2
unnamed: D12.2 (A), R20.2
unnamed: D13.2 (A), R21.2
unnamed: D14.2 (A), R22.2
unnamed: D15.2 (A), R23.2
unnamed: D16.2 (A), R24.2
unnamed: D17.2 (A), R25.2
unnamed: D18.2 (A), R26.2
unnamed: D19.2 (A), R27.2
unnamed: D20.2 (A), R28.2
unnamed: D21.2 (A), R29.2
unnamed: D22.2 (A), R30.2
unnamed: D23.2 (A), R31.2
unnamed: D24.2 (A), R32.2
unnamed: D25.2 (A), R1.2
unnamed: D26.2 (A), R2.2
unnamed: D27.2 (A), R3.2
unnamed: D28.2 (A), R4.2
unnamed: D29.2 (A), R5.2
unnamed: D30.2 (A), R6.2
unnamed: D31.2 (A), R7.2
unnamed: D32.2 (A), R8.2
unnamed: D33.2 (A), R33.2
unnamed: D34.2 (A), R34.2
unnamed: D35.2 (A), R35.2
unnamed: D36.2 (A), R36.2
unnamed: D37.2 (A), R37.2
unnamed: D38.2 (A), R38.2
unnamed: D39.2 (A), R39.2
unnamed: D40.2 (A), R40.2
unnamed: D41.2 (A), R41.2
unnamed: D42.2 (A), R42.2
unnamed: D43.2 (A), R43.2
unnamed: D44.2 (A), R44.2
unnamed: D45.2 (A), R45.2
unnamed: D46.2 (A), R46.2
unnamed: D47.2 (A), R47.2
unnamed: D48.2 (A), R48.2
unnamed: D49.2 (A), R49.2
unnamed: D50.2 (A), R71.2
unnamed: D51.2 (A), R72.2
unnamed: D52.2 (A), R73.2
unnamed: D53.2 (A), R74.2
unnamed: D54.2 (A), R75.2
unnamed: D55.2 (A), R76.2
unnamed: D56.2 (A), R77.2
unnamed: D57.2 (A), R78.2
unnamed: D58.2 (A), R79.2
unnamed: D59.2 (A), R80.2
unnamed: D60.2 (A), R81.2
unnamed: D61.2 (A), R90.2
unnamed: D62.2 (A), R91.2
unnamed: D63.2 (A), R92.2
unnamed: D64.2 (A), R93.2
unnamed: D65.2 (A), R94.2
unnamed: D66.2 (A), R95.2
unnamed: D67.2 (A), R96.2
unnamed: D68.2 (A), R97.2
unnamed: D69.2 (A), R98.2
unnamed: D70.2 (A), R99.2
unnamed: D71.2 (A), R100.2
unnamed: D72.2 (A), R101.2
unnamed: D73.2 (A), R102.2
unnamed: D74.2 (A), R103.2
unnamed: D75.2 (A), R104.2
unnamed: D76.2 (A), R105.2
unnamed: D77.2 (A), R106.2
unnamed: D78.2 (A), R115.2
unnamed: D79.2 (A), R116.2
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

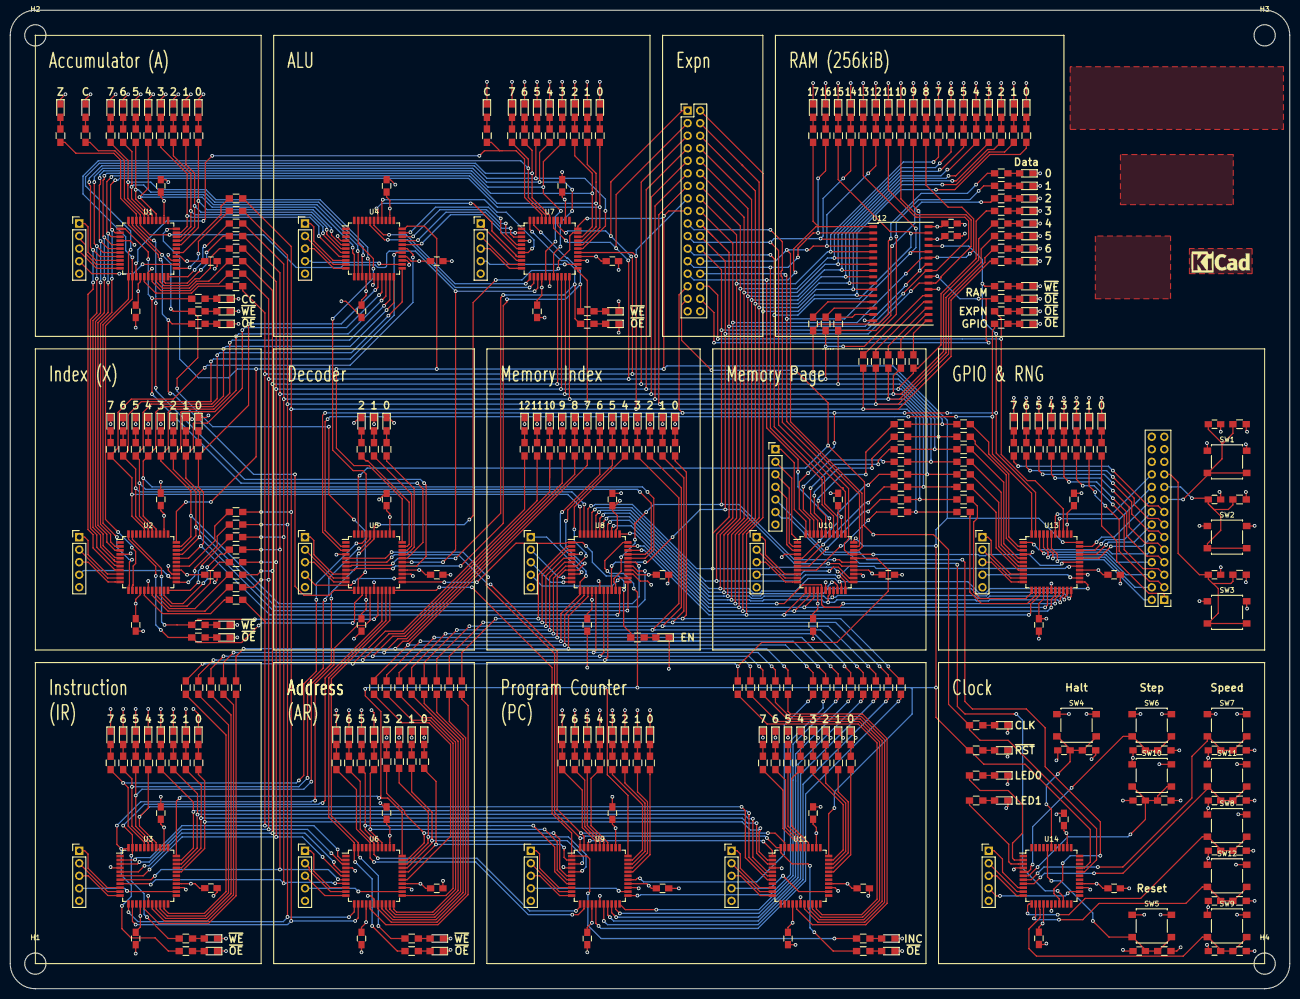
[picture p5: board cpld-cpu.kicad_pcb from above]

Board: 4 copper layers, 259.1 x 198.1 mm, 441 parts (0 on the bottom side), 422 nets.

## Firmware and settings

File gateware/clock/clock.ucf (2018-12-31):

net led0 loc=pin2;
net led1 loc=pin3;
net btn_halt loc=pin39;
net btn_rst loc=pin40;
net btn_step1 loc=pin5;
net btn_step8 loc=pin6;
net btn_s0 loc=pin7;
net btn_s1 loc=pin8;
net btn_s2 loc=pin12;
net btn_s3 loc=pin13;
net btn_s4 loc=pin14;
net prog4 loc=pin19;
net prog5 loc=pin20;
net cpu_clk loc=pin29;
net cpu_rst loc=pin30;
net nrst loc=pin33;

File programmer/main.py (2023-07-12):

import machine
import time

speed = 20

# 7-pin programming header is:
# 0  (unused)       Yellow
# 1  clock    Y9    Green
# 2  data     Y10   Blue
# 3  latch    Y11   Purple
# 4  reset    Y12   Grey
# 5  (unused)       White
# GND               Black

 # prog 4
rst = machine.Pin("Y12", mode=machine.Pin.OUT, pull=machine.Pin.PULL_NONE, value=1)

# prog 1
clk = machine.Pin("Y9", mode=machine.Pin.OUT, pull=machine.Pin.PULL_NONE)
# prog 2
data = machine.Pin("Y10", mode=machine.Pin.OUT, pull=machine.Pin.PULL_NONE)
# prog 3
latch = machine.Pin("Y11", mode=machine.Pin.OUT, pull=machine.Pin.PULL_NONE)


def reset():
    rst.value(0)
    rst.value(1)


def pgm(on=True):
    if on:
        rst.value(0)
    else:
        rst.value(1)


def send(x):
    clk.value(0)
    latch.value(0)

    for i in range(8):
        bit = (x >> (7 - i)) & 1
        data.value(bit)
        clk.value(1)
        clk.value(0)
        time.sleep_us(speed)

    latch.value(1)
    clk.value(1)
    clk.value(0)
    time.sleep_us(speed)
    clk.value(1)
    clk.value(0)
    time.sleep_us(speed)
    latch.value(0)


def erase():
    reset()
    pgm(True)
    for i in range(10000):
        send(0)
    pgm(False)
    reset()
    reset()


def load(data):
    reset()
    pgm(True)
    for b in data:
        send(b)
    pgm(False)
    reset()
    reset()

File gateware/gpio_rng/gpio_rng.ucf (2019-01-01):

net data<0> loc=pin2;
net data<1> loc=pin3;
net data<2> loc=pin5;
net data<3> loc=pin6;
net data<4> loc=pin7;
net data<5> loc=pin8;
net data<6> loc=pin12;
net data<7> loc=pin13;

net addr<0> loc=pin14;
net addr<1> loc=pin18;
net addr<2> loc=pin16;
net addr<3> loc=pin19;
net addr<4> loc=pin20;
net addr<5> loc=pin21;
net addr<6> loc=pin22;
net addr<7> loc=pin23;
net addr<8> loc=pin27;
net page0 loc=pin28;

net gpioa<0> loc=pin39;
net gpioa<1> loc=pin40;
net gpioa<2> loc=pin41;
net gpioa<3> loc=pin42;
net gpioa<4> loc=pin1;
net gpioa<5> loc=pin29;
net gpioa<6> loc=pin30;
net gpioa<7> loc=pin31;

net gpiob<0> loc=pin32;
net gpiob<1> loc=pin37;
net gpiob<2> loc=pin38;

net nwe loc=pin43;
net noe loc=pin44;
net noe_out loc=pin36;
net nrst loc=pin33;

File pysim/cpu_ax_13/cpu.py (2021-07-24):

import sys
from sim import (
    Component,
    Signal,
    NotifySignal,
    IORegister,
    IncRegister,
    Clock,
    Ram,
    Net,
    MemDisplay,
    Multiplexer,
    PagedRamController,
    debug,
    trace,
    warn,
    RNG,
)
from .asm import Assembler


class ALU(Component):
    def __init__(self):
        super().__init__("alu")
        self.a = Signal(self, "a", 9)
        self.b = Signal(self, "b", 8)
        self.out = Signal(self, "out", 9)
        self.fn = Signal(self, "fn", 1)
        self.oe = NotifySignal(self, "oe", 1)
        self.we = NotifySignal(self, "we", 1)
        self.v = 0

    def update(self, signal):
        if self.we.had_edge(0, 1):
            if self.fn.value() == 0:
                # nor
                trace("alu nor {} {}".format(self.a.value(), self.b.value()), end="")
                carry = self.a.value() & 0b100000000
                value = self.a.value() & 0xFF
                self.v = carry | ((~(value | self.b.value())) & 0xFF)
            else:
                # add
                trace("alu add {} {}".format(self.a.value(), self.b.value()), end="")
                self.v = ((self.a.value() & 0xFF) + self.b.value()) & 0x1FF

            trace(" --> {}".format(self.v))

        if self.oe.value() == 1:
            self.out <<= self.v
        else:
            self.out <<= None


class AccumulatorRegister(IORegister):
    def __init__(self):
        super().__init__("accumulator", width=9)
        self.z = Signal(self, "z", 1)
        self.cc = NotifySignal(self, "cc", 1)

    def update(self, signal):
        super().update(signal)
        self.z <<= 1 if self.v == 0 else 0
        if self.cc.had_edge(0, 1):
            self.v = self.v & 0xFF


class Decoder(Component):
    def __init__(self):
        super().__init__("decoder")

        self.clk = NotifySignal(self, "clk", 1)

        self.ram_oe = Signal(self, "ram_oe", 1)
        self.ram_we = Signal(self, "ram_oe", 1)
        self.ar_oe = Signal(self, "ar_oe", 1)
        self.ar_we = Signal(self, "ar_we", 1)
        self.ir_oe = Signal(self, "ir_oe", 1)
        self.ir_we = Signal(self, "ir_we", 1)
        self.pc_we = Signal(self, "pc_we", 1)
        self.pc_oe = Signal(self, "pc_oe", 1)
        self.pc_inc = Signal(self, "pc_inc", 1)
        self.a_oe = Signal(self, "a_oe", 1)
        self.a_we = Signal(self, "a_we", 1)
        self.a_cc = Signal(self, "a_cc", 1)
        self.x_oe = Signal(self, "a_oe", 1)
        self.x_we = Signal(self, "a_we", 1)
        self.alu_oe = Signal(self, "alu_oe", 1)
        self.alu_we = Signal(self, "alu_we", 1)
        self.idx_en = Signal(self, "idx_en", 1)

        self.carry = Signal(self, "carry", 1)
        self.z = Signal(self, "z", 1)

        self.instr = Signal(self, "instr", 3)

        self.state = 0
        self.last_clk = None

    def reset(self):
        self.ram_oe <<= 0
        self.ram_we <<= 0
        self.ar_oe <<= 0
        self.ar_we <<= 0
        self.ir_oe <<= 0
        self.ir_we <<= 0
        self.pc_we <<= 0
        self.pc_oe <<= 0
        self.pc_inc <<= 0
        self.a_oe <<= 0
        self.a_we <<= 0
        self.a_cc <<= 0
        self.x_oe <<= 0
        self.x_we <<= 0
        self.alu_oe <<= 1
        self.alu_we <<= 0
        self.idx_en <<= 0

    def update(self, signal):
        if self.clk.value() != self.last_clk:
            self.state = (self.state + 1) % 8
            self.last_clk = self.clk.value()
        else:
            return
            # print('state: {}: instr: {:02b}'.format(self.state, self.instr.value()))

        self.ram_oe <<= self.state <= 3 or (
            self.instr.value() in (0b000, 0b001, 0b100, 0b101) and self.state <= 5
        )

        self.ar_oe <<= self.state > 3
        self.ir_oe <<= self.state > 3
        self.pc_oe <<= self.state <= 3
        self.ir_we <<= self.state == 1
        self.pc_inc <<= self.state in (
            2,
            4,
        )
        self.ar_we <<= self.state == 3

        # alu
        self.alu_we <<= (
            self.instr.value() in (0b000, 0b001, 0b100, 0b101) and self.state == 5
        )
        # self.alu_oe <<= self.instr.value() in (0b000, 0b001, 0b100, 0b101) and self.state in (5, 6,)
        self.a_we <<= (
            self.instr.value()
            in (
                0b000,
                0b001,
            )
            and self.state == 6
        )
        self.x_we <<= self.instr.value() in (0b100, 0b101) and self.state == 6

        # sta/stx
        self.a_oe <<= self.instr.value() == 0b010 and self.state in (
            5,
            6,
        )
        self.x_oe <<= self.instr.value() == 0b110 and self.state in (
            5,
            6,
        )
        self.ram_we <<= (
            self.instr.value()
            in (
                0b010,
                0b110,
            )
            and self.state == 6
        )

        # Indexing for alu(a), sta
        self.idx_en <<= self.instr.value() in (0b000, 0b001, 0b010) and self.state > 3

        # jcc c=0 / jnz z=0
        self.pc_we <<= (
            (self.instr.value() == 0b011 and self.carry.value() == 0)
            or (self.instr.value() == 0b111 and self.z.value() == 0)
        ) and self.state == 5
        # jcc c=1 / jnz z=1
        self.a_cc <<= (
            (self.instr.value() == 0b011 and self.carry.value() != 0)
            or (self.instr.value() == 0b111 and self.z.value() != 0)
        ) and self.state == 5


class RamIndex(Component):
    def __init__(self):
        super().__init__("ram_index")
        self.addr = NotifySignal(self, "addr", 12)
        self.x = NotifySignal(self, "x", 8)
        self.out = Signal(self, "out", 12)
        self.en = NotifySignal(self, "en", 1)

    def update(self, signal):
        if self.en.value():
            # print('offset by {}'.format(self.x.value()))
            self.out <<= self.addr.value() + self.x.value()
        else:
            self.out <<= self.addr.value()
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

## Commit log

2017-11-04 Rewrite to make all nets single-wire.
2017-11-04 Update CPU to use new single-wire simulator
2017-12-20 simple macro-assembler helpers
2017-12-23 Add a simple parser/assembler.
    [asm.g]
2017-12-24 Remaining jump and alu ops.
    [asm.g]
2017-12-24 Add a simple test that does something N times.
    [asm.g]
2017-12-25 Add a basic compiler and a test program.
    [asm.g, zz.g]
2017-12-25 Add a stack pointer and return address stack, and call/ret functions.
    [asm.g, zz.g]
2017-12-25 Add mod and is_prime tests.
    [zz.g]
2018-11-27 Implement clone of the CPLD CPU from https://github.com/cpldcpu/MCPU
    [asm.g, zz.g]
2018-11-29 Extend tinycpu to add an index register
    [asm.g]
2018-11-30 Rename tinycpu->mcpu (to match what it is based on), and indexcpu->mxcpu to match
    [asm.g]
2018-11-30 Simplify implementation of v2a, use more constants
    [asm.g]
2018-12-02 Add paged memory controller
    [asm.g]
2018-12-03 Add page/ldpg macros
    [asm.g]
2018-12-08 Split the A+X cpu into discrete components
    [asm.g, zz.g]
2018-12-09 Add Kicad symbols, start schematic
    [cpld-cpu.kicad_pcb, cpld-cpu.sch]
2018-12-09 Most of the schematic done (just missing RAM/mmappedio)
    [cpld-cpu.kicad_pcb, cpld-cpu.sch]
2018-12-09 Ram connections
    [cpld-cpu.sch]
2018-12-10 Reduce num pages to 64
    [cpld-cpu.kicad_pcb, cpld-cpu.sch]
2018-12-10 Add RAM
    [cpld-cpu.kicad_pcb, cpld-cpu.sch]
2018-12-13 Fix base_addr
    [cpld-cpu.kicad_pcb]
2018-12-13 Lay PCB, most parts except busses
    [cpld-cpu.kicad_pcb, cpld-cpu.sch]
2018-12-13 routing a/x/alu
    [cpld-cpu.kicad_pcb]
2018-12-17 VHDL for ioregister and program_counter.
    [xc9572xl-ft232r.cfg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]
2018-12-17 VHDL for alu/decoder/multiplexer
    [cpld-cpu.kicad_pcb, cpld-cpu.sch]
2018-12-17 More routing
    [cpld-cpu.kicad_pcb]
2018-12-18 Simplify mem oe/we interface. Makes more pins available on mem_page.
    [cpld-cpu.kicad_pcb, cpld-cpu.sch]
2018-12-18 VHDL for mem_index
    [cpld-cpu.kicad_pcb, cpld-cpu.sch]
2018-12-19 Route data bus
    [cpld-cpu.kicad_pcb, cpld-cpu.sch]
2018-12-19 Clock schematic
    [cpld-cpu.kicad_pcb, cpld-cpu.sch]
2018-12-19 Clock routing
    [cpld-cpu.kicad_pcb, cpld-cpu.sch]
2018-12-20 Finished ratsnest
    [cpld-cpu.kicad_pcb, cpld-cpu.sch]
2018-12-20 Passed DRC
    [cpld-cpu.kicad_pcb]
2018-12-20 Add logos and version
    [cpld-cpu.kicad_pcb, cpld-cpu.sch]
2018-12-20 Name inverted nets correctly
    [cpld-cpu.kicad_pcb, cpld-cpu.sch]
2018-12-20 First gerbers
    [cpld-cpu-B.Cu.gbr, cpld-cpu-B.Mask.gbr, cpld-cpu-Edge.Cuts.gbr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]
2018-12-20 Updated gerbers for seeed/jlcpcb
    [cpld-cpu-B.Cu.gbl, cpld-cpu-B.Mask.gbr, cpld-cpu-B.Mask.gbs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]
2018-12-20 Remove R/C/J/D labels from silkscreen
    [cpld-cpu-B.Cu.gbl, cpld-cpu-B.Mask.gbs, cpld-cpu-Edge.Cuts.gm1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]
2018-12-21 Add schematic
2018-12-31 It works!
    [xc9572xl-ft232r.cfg]
2019-01-01 Use new non-clocked PC. Fix carry handling in ALU amd Z handling in Acc. Fix cc/pc_we in Decoder. Make clock run up to 250kHz. Fix GPIO inputs. New tests and demos.
    [gpio_rng.ucf]
2019-01-10 APA102C demo
    [asm.g]
2023-07-12 programmer/main.py: Add pin descriptions.
